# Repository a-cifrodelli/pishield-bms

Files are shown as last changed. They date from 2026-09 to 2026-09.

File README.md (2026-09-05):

# 🛡️ PiShield BMS - Smart UPS & BMS for Raspberry Pi / SBC







**PiShield BMS** è un sistema **UPS (Uninterruptible Power Supply)** personalizzato e modulare dotato di **BMS (Battery Management System)** intelligente basato su Arduino Nano, progettato per garantire l'alimentazione continua e lo spegnimento sicuro (*graceful shutdown*) di un Raspberry Pi o altro Single Board Computer Linux.

> [!WARNING]
> **Work In Progress (WIP)**: Il progetto è in fase di affinamento. La custodia / enclosure stampata in 3D per alloggiare l'elettronica è stata prototipata ma non ha ancora raggiunto una maturità progettuale idonea per la pubblicazione (versione definitiva in corso di perfezionamento).

---

## 💡 Motivazione e Filosofia del Progetto

Il progetto nasce dalla necessità di realizzare un UPS con BMS integrato per Raspberry Pi **senza dover ricorrere alle schede commerciali preassemblate in formato HAT**. 

I moduli HAT commerciali presentano spesso limiti quali:
* Scarsa personalizzazione delle soglie di sicurezza e dei tempi di spegnimento.
* Assenza di protezione termica attiva sulle singole celle 18650.
* Impossibilità di effettuare uno sgancio fisico (*hard cutoff*) per preservare le batterie da scarica profonda e degrado chimico.
* Ingombro rigido sovrapposto al Raspberry Pi.

**PiShield BMS** unisce un economico modulo UPS base con circuito di carica/boost (LX-2BUPS) ad una logica di controllo dedicata su **Arduino Nano**, garantendo la massima sicurezza hardware e flessibilità software.

---

## 📚 Indice della Documentazione

Tutta la documentazione di dettaglio è organizzata nella cartella `docs/`:

* 🛠️ **[Guida alla Ricreazione Hardware (BOM, Cablaggio e Saldature)](docs/recreate.md)**: Elenco componenti (BOM), schema elettrico, istruzioni per le saldature custom ed adattamento del modulo mini UPS base.
* 🚀 **[Guida al Deployment e Installazione Software](docs/deploy.md)**: Configurazione della seriale su Raspberry Pi, script di installazione automatica (`install.sh`), configurazione Systemd e comandi CLI (`pishield-bms`).
* 🧪 **[Piano di Test di Integrazione e Simulazione](docs/TEST_PLAN.md)**: Scenari di test simulati (`TEST_MODE`) per validare spegnimenti, blackout, recovery ed emergency cutoff.

---

## ✨ Funzionalità Principali

* **Doppia Protezione Batterie (Hard Cutoff & Graceful Shutdown)**:
  * **Spegnimento Morbido (Graceful Shutdown)**: Invia una richiesta seriale `SHUTDOWN_REQ` al Raspberry Pi al superamento di soglie di warning (tensione batteria `< 3.2V` o temperatura `> 70°C`).
  * **Sgancio di Emergenza (Hard Cutoff)**: Disattiva il relè KY-019 per staccare fisicamente il pacco batterie in condizioni estreme (tensione batteria `< 3.0V` o temperatura `> 75°C`).
* **Stadi di Protezione Ingressi Analogici**:
  * Lettura filtrata delle tensioni di rete e batteria tramite partitori protetti da fusibili autoripristinanti PPTC (`X16 CF110`) e diodi Schottky (`1N5819`).
* **Monitoraggio Termico**:
  * Misurazione della temperatura su 2 zone/celle tramite termistori NTC 100kΩ.
* **Interfaccia OLED SSD1306 (128x32)**:
  * Visualizzazione in tempo reale di tensioni, temperature, stato della rete, stato delle batterie e calcolo del SOC % con testo in scorrimento continuo.
* **Integrazione Host (Raspberry Pi)**:
  * Client Python (`bms_integration.py` con `config.py` e `.env`) gestito da demone Systemd (`pishield-bms.service`) per la gestione automatica degli ACK di spegnimento e pubblicazione dello stato su broker **MQTT**.
* **Ripristino Automatico (Auto-Recovery)**:
  * Riaggancio automatico del relè quando viene ripristinata la rete elettrica principale e le temperature tornano nella norma.

---

## 🔌 Schema Elettrico di Sintesi

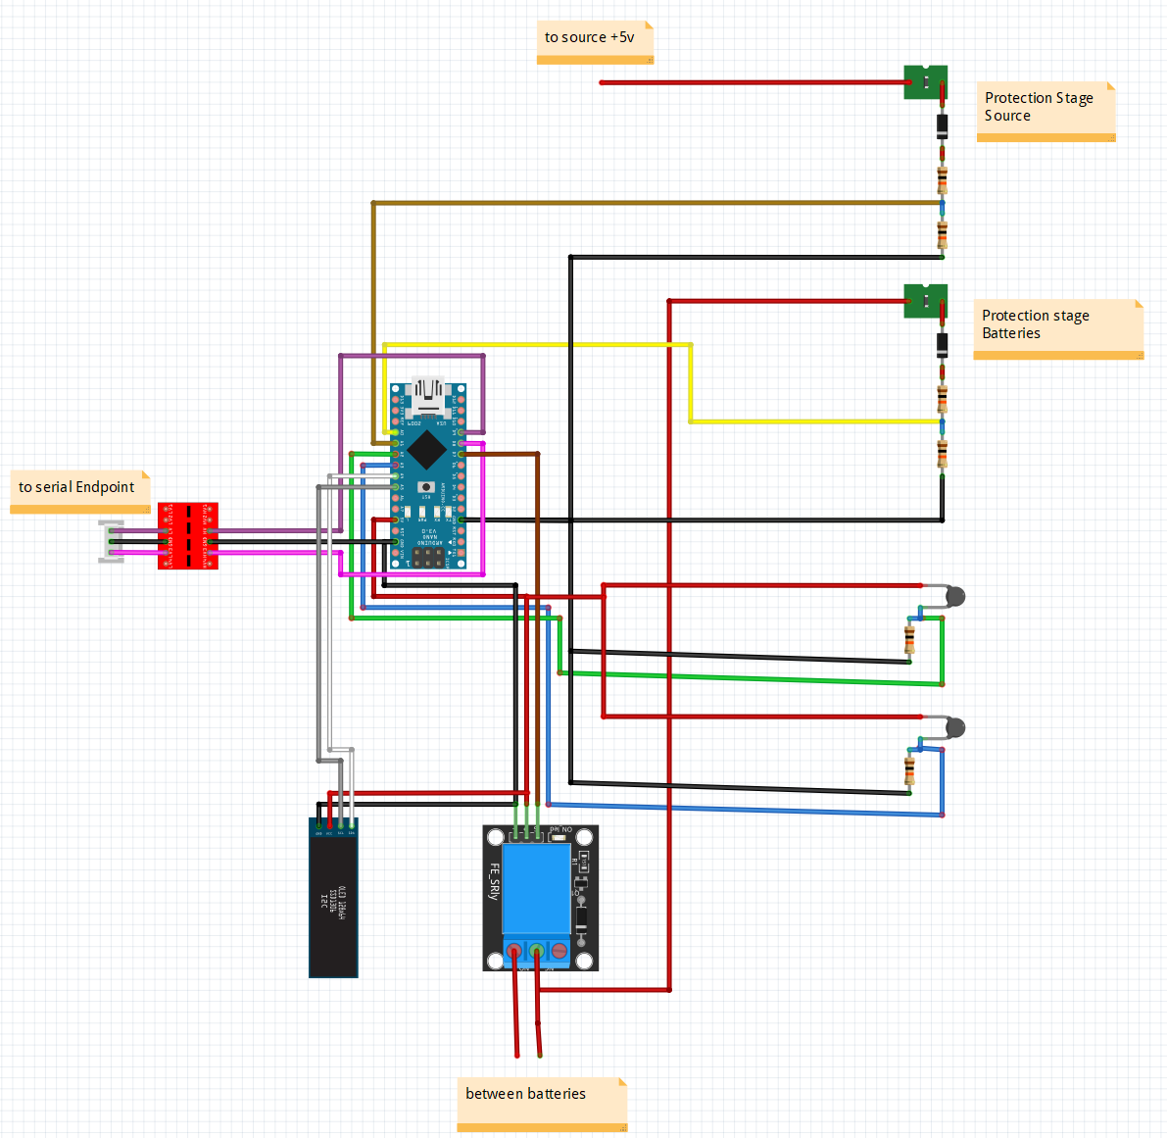
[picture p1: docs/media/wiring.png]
Diagramma di Cablaggio


Per i dettagli completi sul cablaggio e sulle saldature, fare riferimento alla **[Guida alla Ricreazione Hardware](docs/recreate.md)**.

---

## 📄 Licenza

Questo progetto è rilasciato sotto licenza **[MIT License](LICENSE)**.

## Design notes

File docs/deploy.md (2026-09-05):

# 🚀 Guida al Deployment e Installazione Software (PiShield BMS)

Questa guida descrive la procedura di installazione e configurazione del software di integrazione su **Raspberry Pi** (o altro Single Board Computer Linux) per la gestione della comunicazione seriale, il log degli eventi e l'arresto controllato del sistema operativo (*graceful shutdown*).

---

## 📋 Requisiti Preliminari

1. **Sistema Operativo**: Raspberry Pi OS (o altra distribuzione Linux basata su Debian).
2. **Connessione Seriale**:
   * Collegamento UART tra Arduino Nano (tramite traslatore di livello logico 3.3V-5V) ed il Raspberry Pi (su porta `/dev/ttyUSB0` o GPIO UART `/dev/ttyAMA0` / `/dev/ttyS0`).
3. **Abilitazione UART su Raspberry Pi**:
   * Eseguire `sudo raspi-config` -> `Interface Options` -> `Serial Port`.
   * Disabilitare la console di login sulla seriale (*Would you like a login shell to be accessible over serial?* -> **No**).
   * Abilitare l'hardware della porta seriale (*Would you like the serial port hardware to be enabled?* -> **Yes**).
   * In alternativa, verificare che in `/boot/firmware/config.txt` (o `/boot/config.txt`) sia presente la riga:
     ```ini
     enable_uart=1
     ```

---

## ⚡ Installazione Automatica via Script (`install.sh`)

È fornito uno script bash automatizzato in `integration/install.sh` che gestisce la creazione dell'ambiente virtuale Python (`venv`), l'installazione delle dipendenze da `requirements.txt`, la copia dei file in `/opt/pishield_bms`, la configurazione dei permessi e l'attivazione del servizio Systemd `pishield-bms.service`.

### Procedura di Installazione

1. Clonare il repository sul Raspberry Pi:
   ```bash
   git clone https://github.com/username/pishield_bms.git
   cd pishield_bms/integration
   ```

2. Rendere eseguibile ed avviare lo script di installazione con i privilegi di root:
   ```bash
   chmod +x install.sh launcher.sh
   sudo ./install.sh
   ```

---

## ⚙️ Operazioni Eseguite dall'Installer

Lo script di installazione esegue automaticamente i seguenti passaggi:

1. **Installazione Pacchetti di Sistema**:
   * Installa `python3`, `python3-venv` e `python3-pip`.
2. **Setup della Directory di Servizio (`/opt/pishield_bms`)**:
   * Copia i file del modulo: `bms_integration.py`, `config.py`, `requirements.txt`, `launcher.sh` e crea un file `.env` basato su `.env.example`.
3. **Ambiente Virtuale Python (Venv)**:
   * Inizializza l'ambiente virtuale in `/opt/pishield_bms/venv` ed installa le dipendenze isolate definite in `requirements.txt` (`pyserial`, `paho-mqtt`, `python-dotenv`).
4. **Configurazione Symlink Globale**:
   * Crea i link simbolici `/usr/local/bin/pishield-bms` ed `/usr/local/bin/bms_integration` -> `/opt/pishield_bms/launcher.sh` per consentire l'esecuzione da qualsiasi terminale.
5. **Configurazione Permessi Sudoers**:
   * Crea il file `/etc/sudoers.d/pishield-bms` per consentire l'esecuzione del comando `/sbin/shutdown` senza richiesta di password:
     ```text
     ALL ALL=(ALL) NOPASSWD: /sbin/shutdown
     ```
6. **Attivazione Servizio Systemd**:
   * Installa ed abilita `/etc/systemd/system/pishield-bms.service` avviando in background `/opt/pishield_bms/launcher.sh ack`.

---

## 🛠️ Personalizzazione tramite File `.env`

Le impostazioni del client (porta seriale, baudrate, file di log e parametri MQTT) sono centralizzate in `config.py` e possono essere personalizzate modificando il file `/opt/pishield_bms/.env`:

```env
SERIAL_PORT=/dev/ttyUSB0
BAUDRATE=115200
LOGFILE=/var/log/pishield_bms.log
SUFFIX_FILTER=LOG

MQTT_HOST=localhost
MQTT_PORT=8883
MQTT_USER=
MQTT_PASSWORD=
MQTT_TLS=false
MQTT_CA_CERTS=
```

---

## 🔍 Verifiche e Utilizzo CLI

### Verificare lo Stato del Servizio
Per controllare che il servizio in background stia ascoltando correttamente i comandi seriali dall'Arduino:

```bash
systemctl status pishield-bms.service
```

Per consultare i log del servizio tramite `journalctl`:
```bash
journalctl -u pishield-bms.service -f
```

### Utilizzo dei Comandi CLI Manuali
Il comando `pishield-bms` invoca lo script `launcher.sh` eseguendo la logica nel venv dedicato:

* **Test Connessione (PING)**:
  ```bash
  pishield-bms ping
  ```
* **Ascolto e Log Seriale**:
  ```bash
  pishield-bms listen
  ```
* **Lettura Log Salvati**:
  ```bash
  pishield-bms logs -f
  ```
* **Forzatura Spegnimento Manuale**:
  ```bash
  pishield-bms shutdown
  ```

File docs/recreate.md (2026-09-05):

# 🛠️ Guida alla Ricreazione Hardware (PiShield BMS)

Questa guida illustra come assemblare e ricreare l'hardware del sistema **PiShield BMS** seguendo il diagramma di cablaggio ed eseguendo le modifiche necessarie sul modulo UPS base.

> [!WARNING]
> **Work In Progress (WIP)**: Il progetto è in fase di affinamento. La custodia / enclosure stampata in 3D progettata per alloggiare l'intera elettronica è stata prototipata ma non ha ancora raggiunto una maturità progettuale idonea per la pubblicazione (versione definitiva in corso di perfezionamento).

---

## 📦 Bill of Materials (BOM)

| Item | Qty | Specifiche / Descrizione |
| :--- | :---: | :--- |
| **Resistenze 10kΩ** | 4 | Resistenze a strato metallico per i partitori di tensione analogici (A0 e A1) |
| **Resistenze 100kΩ** | 2 | Resistenze fisse per i partitori dei termistori NTC |
| **Termistori NTC 100kΩ** | 2 | Termistori NTC NTC-104 (BETA 3950) per monitoraggio temperatura celle |
| **Fusibili PPTC Autoripristinanti** | 2 | Fusibili PPTC siglati `X16 CF110` (1.1A / 16V) per stadio di protezione ingressi |
| **Diodi Schottky 1N5819** | 2 | Diodi Schottky `1N5819` per protezione da tensioni inverse sui canali ADC |
| **Modulo Relè 5V (KY-019)** | 1 | Modulo relè 5V optoisolato per lo sgancio fisico delle batterie |
| **Display OLED I2C 128x32** | 1 | Display SSD1306 I2C per interfaccia utente locale |
| **Modulo Mini UPS (LX-2BUPS)** | 1 | Scheda UPS 3A / 5V boost con alloggiamento per 2x 18650 in parallelo |
| **Arduino Nano V3** | 1 | Microcontrollore ATmega328P (logica 5V) |
| **Logic Level Shifter (CYT1076)** | 1 | Convertitore di livello logico bidirezionale 3.3V <-> 5V a 4 canali per bus UART |
| **Modulo Uscita USB-C Breakout** | 1 | Modulo USB-C con resistenze 56kΩ su CC1 e CC2 (configurazione 3A Source) |
| **Condensatore ceramico 0.1µF** | 1 | Condensatore di disaccoppiamento tra VCC e GND su Arduino Nano |
| **Resistenza 1kΩ** | 1 | Resistenza in serie sulla linea seriale TX Arduino -> Level Shifter |
| **Nastro Kapton e Cavi di Potenza** | - | Nastro isolante Kapton e cavi AWG18-20 (potenza) e AWG24-26 (segnali) |

---

## 📸 Componenti e Diagramma di Cablaggio

### Modulo Mini UPS di Base (LX-2BUPS)
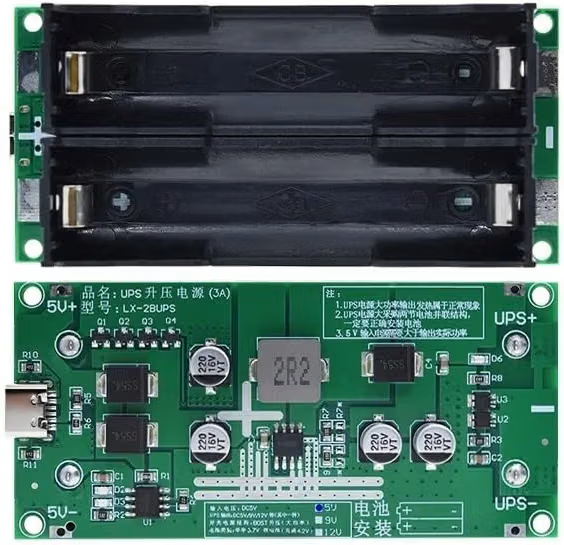
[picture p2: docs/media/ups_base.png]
Modulo Mini UPS Base


### Schema Elettrico Globale
Diagramma di Cablaggio

---

## 🔬 Saldature e Modifiche Hardware Custom

Per integrare la logica BMS ed il relè di protezione con il modulo UPS base (LX-2BUPS), è necessario eseguire le seguenti modifiche hardware:

### 1. Dissaldatura dai Moduli Originali
1. **Contatti Batterie**: Dissaldare con cura le linguette o i contatti a molla originali delle batterie dal PCB dell'UPS LX-2BUPS (o intercettare i terminali del connettore batteria).
2. **Uscita 5V Originale**: Dissaldare i pin/connettori d'uscita 5V dal PCB dell'UPS per reindirizzarli al modulo USB-C dedicato.

### 2. Collegamento del Relè di Sgancio (KY-019)
* Saldare cavi di potenza con sezione adeguata (**AWG 18-20**) tra il polo positivo del pacco batterie (2x 18650) ed i morsetti `COM` e `NO` del relè KY-019.
* **Sicurezza del Pacco Batterie in Parallelo**:
  > [!NOTE]
  > L'analisi del PCB del modulo LX-2BUPS conferma che le due celle 18650 sono collegate nativamente in **parallelo puro** alla stessa linea di carica/scarica. È quindi del tutto sicuro interrompere il polo positivo comune del ramo batterie tramite il relè: il modulo continuerà a gestire il bilanciamento passivo e la carica/scarica in modo bilanciato senza rischiare sbilanciamenti di cella.

### 3. Modulo Uscita USB-C con Configurazione 3A (Source)
* Collegare le piazzole di uscita 5V boost del modulo UPS (`UPS+` e `UPS-`) agli ingressi di alimentazione del modulo USB-C breakout.
* Assicurarsi che sul breakout USB-C i pin **CC1** e **CC2** siano pull-uppati a VCC tramite resistenze da **56kΩ**. Questa configurazione informa il carico (ad esempio una Raspberry Pi 4 o 5 gestita come *Sink*) che la sorgente USB-C è in grado di erogare fino a **3A a 5V**.

### 4. Stadi di Protezione Ingressi Analogici Arduino
Realizzare i due stadi di protezione (per la sorgente di rete e per la batteria) facendo riferimento al [Diagramma di Cablaggio](#schema-elettrico-globale):

* **Ingresso Rete**: Collegare il polo positivo dell'ingresso USB-C principale allo stadio di protezione Sorgente (PPTC `X16 CF110` -> Diodo `1N5819` -> partitore 10kΩ/10kΩ) con punto di misura collegato al pin `PINRETE` (**A1** Arduino).
* **Ingresso Batteria**: Collegare il polo positivo a valle del relè allo stadio di protezione Batterie (PPTC `X16 CF110` -> Diodo `1N5819` -> partitore 10kΩ/10kΩ) con punto di misura collegato al pin `PINBATT` (**A0** Arduino).

### 5. Sensori di Temperatura NTC e Display OLED
* Collegare i due termistori NTC 100kΩ in serie con la relativa resistenza fissa da 100kΩ verso i pin **A2** (`PINNTC1`) e **A3** (`PINNTC2`).
* Collegare il display OLED I2C 128x32: `SDA` -> **A4**, `SCL` -> **A5**, `VCC` -> **5V**, `GND` -> **GND**.

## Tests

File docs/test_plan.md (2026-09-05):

# 🧪 Piano di Test di Integrazione PiShield BMS

Questo documento illustra i piani di test per validare la logica del BMS **PiShield BMS**.
Imposta `#define TEST_MODE true` in `config.h` per abilitare i comandi seriali.

---

<details open>
<summary><b>🌩️ 1. Blackout con batteria debole (Warning)</b></summary>

* **Input Seriale:** `SIM_GRID 0` poi `SIM_BATT 3.1`
* **Stato Simulato:** Manca la rete (Offgrid) e la batteria è scesa sotto la soglia di warning (3.2V).
* **Risultato Atteso:** 
  > Il sistema entra in stato `BAT LOW` e `OFFGRID`.
  > Stampa **`SHUTDOWN_REQ`** e inizia un conto alla rovescia (60s) avvisando `SHUTDOWN IMMINENT`. 
  > Il relè rimane *chiuso*.

</details>

<details>
<summary><b>🔌 2. Ripristino Rete durante il Countdown</b></summary>

* **Input Seriale:** `SIM_GRID 5.0` *(durante il test 1)*
* **Stato Simulato:** La corrente elettrica torna prima dello scadere del timer di sicurezza.
* **Risultato Atteso:** 
  > Il sistema riconosce `ONGRID`. 
  > Il timer di spegnimento viene **interrotto e annullato**. 
  > Il sistema riprende il normale funzionamento, il relè non stacca.

</details>

<details>
<summary><b>🤝 3. Acknowledge (Spegnimento RPi)</b></summary>

* **Input Seriale:** `SIM_GRID 0` ➔ `SIM_BATT 3.1` ➔ `ACK`
* **Stato Simulato:** Blackout e batteria debole. Il Raspberry Pi risponde con "ACK" per confermare lo spegnimento imminente.
* **Risultato Atteso:** 
  > Il sistema riceve `ACK` e stampa **`WAITING`**. 
  > Il cooldown viene forzatamente **ridotto a 30s** per velocizzare lo stacco di sicurezza.

</details>

<details>
<summary><b>💀 4. Batteria Critica (Hard Cutoff)</b></summary>

* **Input Seriale:** `SIM_GRID 0` poi `SIM_BATT 2.9`
* **Stato Simulato:** La batteria scende sotto la soglia letale (3.0V). Rischio di danneggiamento chimico.
* **Risultato Atteso:** 
  > Nessun conto alla rovescia. 
  > Stampa **`!!! EMERGENCY CUTOFF TRIGGERED !!!`** con reason **`BATTERY_CRITICAL_AND_OFFGRID`** e **stacca il relè istantaneamente** per salvare la batteria.

</details>

<details>
<summary><b>🔥 5. Surriscaldamento (Warning)</b></summary>

* **Input Seriale:** `SIM_TEMP 71`
* **Stato Simulato:** L'NTC rileva una temperatura superiore ai 70°C.
* **Risultato Atteso:** 
  > Il sistema entra in `TEMP WARNING`. 
  > Stampa **`SHUTDOWN_REQ`** e avvia il cooldown per far spegnere dolcemente il RPi.

</details>

<details>
<summary><b>🌋 6. Surriscaldamento Critico (Thermal Cutoff)</b></summary>

* **Input Seriale:** `SIM_TEMP 80`
* **Stato Simulato:** Temperatura oltre i 75°C. Rischio di esplosione o incendio.
* **Risultato Atteso:** 
  > Stampa **`!!! EMERGENCY CUTOFF TRIGGERED !!!`** con reason **`TEMPERATURE_CRITICAL`** e **stacca il relè istantaneamente**.

</details>

<details>
<summary><b>🛑 7. Spegnimento Manuale Diretto</b></summary>

* **Input Seriale:** `SHUTDOWN_NOW`
* **Stato Simulato:** Utente forza lo spegnimento immediato per manutenzione.
* **Risultato Atteso:** 
  > Stampa **`SHUTDOWN REASON: user_choice`**. 
  > Inizia a stampare **`SHUTDOWN IMMINENT - COOLDOWN: ...`** ogni secondo in modo fluido.
  > Attende 15 secondi esatti e poi disattiva il relè. Non è interrompibile se torna la rete.

</details>

<details>
<summary><b>✅ 8. Ripristino da Sicurezza</b></summary>

* **Input Seriale:** `SIM_RESET` (oppure `SIM_GRID 5.0` e `SIM_TEMP 25`)
* **Stato Simulato:** Rete elettrica ripristinata e temperature tornate normali.
* **Risultato Atteso:** 
  > Stampa **`[RECOVERY] Rete ripristinata e temperatura sicura. Riattacco il rele'.`**.
  > I log tornano a indicare `ONGRID` e `T:OK`. Il BMS rientra a regime normale ricaricando la batteria.

</details>

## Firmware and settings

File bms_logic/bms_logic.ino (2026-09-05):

#include "config.h"
#include "sensor.h"
#include "display.h"
#include "log.h"
#include "terminal.h"
#include "shutdown.h"
#include "bms_state.h"
Shudown_Req shutdown_req;
bool cutoff_now = false;

void executeEmergencyCutoff(const __FlashStringHelper* reason) {
  if (cutoff_now) return; // Evita di spammare la seriale se è già staccato
  
  digitalWrite(RELAYPIN, LOW); // SGANCIO FISICO IMMEDIATO
  cutoff_now = true;

  Serial.println(F("\n================================="));
  Serial.print(F("!!! EMERGENCY CUTOFF TRIGGERED !!!\nREASON: "));
  Serial.println(reason);
  Serial.println(F("=================================\n"));
}

// Le logiche di shutdown sono state spostate in shutdown.cpp

void setup() {
  Serial.begin(115200);
  delay(100); // Breve assestamento per la seriale

  Serial.println(F("\n================================="));
  Serial.println(F("   PISHIELD BMS - BOOTING...     "));
  Serial.println(F("================================="));
  
  Serial.println(F("[BOOT] Setup Pin I/O..."));
  pinMode(RELAYPIN, OUTPUT);
  pinMode(PINBATT, INPUT);
  pinMode(PINRETE, INPUT);
  pinMode(PINNTC1, INPUT);
  pinMode(PINNTC2, INPUT);
  
  Serial.println(F("[BOOT] Init Shutdown Logic..."));
  initRequestShutdown();
  
  Serial.println(F("[BOOT] Init OLED Display..."));
  initDisplay();
  
  Serial.println(F("[BOOT] Attivazione Rele' OUT..."));
  digitalWrite(RELAYPIN, HIGH);
  
  Serial.println(F("================================="));
  Serial.println(F("     SISTEMA PRONTO ALL'USO      "));
  Serial.println(F("================================="));

  delay(2000);
}

void loop() {
  // LETTURE SENSORI
  float vbatt = readBattVoltage();
  float soc = voltageToSOC(vbatt);
  float temp1 = readTemperature(PINNTC1);
  float temp2 = readTemperature(PINNTC2);
  float temp  = max(temp1, temp2); // prende la peggiore
  float vrete = readGridVoltage();

  // AGGIORNO STATO
  updateBMSState(vbatt, temp, vrete);

  // --- CUTOFF IMMEDIATI ---
  if(tempstate == TEMP_CRITICAL){
    executeEmergencyCutoff(F("TEMPERATURE_CRITICAL"));
  }
  if((batstate == BAT_CRITICAL) && (gridstate == OFFGRID)){
    executeEmergencyCutoff(F("BATTERY_CRITICAL_AND_OFFGRID"));
  }

  // --- SHUTDOWN RITARDATI (WARNING) ---
  if (!cutoff_now) {
    bool need_shutdown = false;
    if (tempstate == TEMP_WARNING) need_shutdown = true;
    if ((batstate == BAT_LOW) && (gridstate == OFFGRID)) need_shutdown = true;

    if (need_shutdown) {
      requestShutdown();
      shutdown_req.can_interrupt_shutdown = false; // L'allarme è attivo, spegnimento in corso
    } else {
      // Tutto regolare. Se c'era uno spegnimento in corso (non forzato dall'utente), annullalo.
      if (!shutdown_req.user_forced) {
        shutdown_req.can_interrupt_shutdown = true;
      }
    }
  }

  // AUTO-RECOVERY (Es. per Scenario 8 del piano di test)
  if (cutoff_now && gridstate == ONGRID && tempstate == TEMP_NORMAL && !shutdown_req.user_forced) {
     Serial.println(F("[RECOVERY] Rete ripristinata e temperatura sicura. Riattacco il rele'."));
     cutoff_now = false;
     digitalWrite(RELAYPIN, HIGH);
  }
  //SERIALE E COOLDOWN TIME-SPLICING
  checkShutdownCooldown();
  handleSerial();
  //LOG &DISPLAY
  updateDisplay(vbatt, temp1, temp2, vrete, soc, batstate, tempstate, gridstate);
  periodic_log(vbatt, temp1, temp2, vrete, soc, batstate, tempstate, gridstate);
  delay(GLOBAL_TICK);
}

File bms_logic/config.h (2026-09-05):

#ifndef CONFIG
#define CONFIG

// ===============================
// DISPLAY
// ===============================
#define SCREEN_WIDTH 128
#define SCREEN_HEIGHT 32

// ===============================
// HARDWARE PINS
// ===============================
#define PINBATT A0
#define PINRETE A1
#define PINNTC1 A2   // NTC cella 1
#define PINNTC2 A3   // NTC cella 2
#define RELAYPIN 4    // relay sgancio batterie
#define RXPIN 8   // RX Arduino (collegato a TX RPi)
#define TXPIN 9   // TX Arduino (collegato a RX RPi)

// ===============================
// PARTITORI (da adattare ai tuoi valori)
// ===============================
const float R1 						= 10000.0;   // 10kΩ
const float R2 						= 10000.0;   // 10kΩ

// ===============================
// NTC 
// ===============================
const float R_FIXED 			    = 100000.0; // resistenza fissa 100k
const float BETA 					= 3950.0;      // parametro del datasheet
const float T0 						= 298.15;        // 25 °C in Kelvin
const float R0 						= 100000.0;      // resistenza NTC a 25°C

// ===============================
// SOGLIE DI SICUREZZA
// ===============================
const float VBATLOW					= 3.2;//3.3;   // V soglia warning
const float VBATHIGH     			= 3.7;//3.7;   // V isteresi riattacco
const float VBATCRITICAL 			= 3.0;   // V hard cutoff

const float TEMPWARN      			= 70.0;  // °C warning
const float TEMPCRITICAL  			= 75.0;  // °C hard cutoff
const float TEMPNORMAL          = 40;

const float GRIDLOW         = 4.0;

// Gli enumeratori di stato sono stati spostati in bms_state.h

// ===============================
// CONFIG FLAG
// ===============================
#define SERIAL_DEBUG true   // se true abilita PING/PONG e log verbosi
#define TEST_MODE false      // se true usa dati fittizi per i sensori (mock)
#if TEST_MODE
#define MOCK_DEFAULT_VBATT 4.0
#define MOCK_DEFAULT_VRETE 5.0
#define MOCK_DEFAULT_TEMP 25.0
#endif
#define GLOBAL_TICK 200

// ===============================
// COOLDOWN
// ===============================
const unsigned int MIN_SHUTDOWN_COOLDOWN = 30000;
const unsigned int MAX_SHUTDOWN_COOLDOWN = 60000;
const unsigned int USER_CHOICE_SHUTDOWN_COOLDOWN = 15000;

typedef struct Shudown_Req{
  bool requested;
  bool can_interrupt_shutdown;
  bool user_forced;
  unsigned long started_at;
  unsigned long cooldown;
  unsigned long cooldown_lastprint;
};

#endif

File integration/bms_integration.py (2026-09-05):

#!/usr/bin/env python3
import argparse
import serial
import sys
import time
import os
import threading
import atexit
import paho.mqtt.client as mqtt

import config

SERIAL_CONN = None

def publish_mqtt(topic: str, message: str,
                 host=config.MQTT_HOST, port=config.MQTT_PORT,
                 user=config.MQTT_USER, password=config.MQTT_PASSWORD,
                 tls_enabled=config.MQTT_TLS, tls_ca=config.MQTT_CA_CERTS,
                 keepalive=60):
    try:
        client = mqtt.Client()
        if user and password:
            client.username_pw_set(user, password)
        if tls_enabled:
            if tls_ca:
                client.tls_set(ca_certs=tls_ca)
            else:
                client.tls_set()  # usa certificati default
        client.connect(host, port, keepalive)
        client.publish(topic, message)
        client.disconnect()
        print(f"MQTT pubblicato → {topic}: {message}")
    except Exception as e:
        print(f"Errore MQTT: {e}")

def open_serial():
    global SERIAL_CONN
    SERIAL_CONN = serial.Serial(config.SERIAL_PORT, config.BAUDRATE, timeout=1)
    return SERIAL_CONN

def cleanup():
    if SERIAL_CONN and SERIAL_CONN.is_open:
        SERIAL_CONN.close()
        print("Seriale chiusa correttamente.")

def write_log(line: str):
    """Scrive log filtrato su file"""
    if line.endswith(config.SUFFIX_FILTER):
        return
    try:
        with open(config.LOGFILE, "a") as f:
            f.write(line.strip() + "\n")
    except Exception as e:
        print(f"Errore scrittura log su {config.LOGFILE}: {e}")

def read_serial(ser):
    """Legge una riga dalla seriale"""
    try:
        line = ser.readline().decode(errors="ignore").strip()
        if line:
            print(line)       # output sempre completo a schermo
            write_log(line)   # log filtrato
        return line
    except Exception:
        return ""

# ---------------------------
# COMMANDS
# ---------------------------
def cmd_shutdown():
    ser = open_serial()
    ser.write(b"SHUTDOWN_NOW\n")
    print("Inviato: SHUTDOWN_NOW")

def cmd_ping():
    ser = open_serial()
    ser.write(b"PING\n")
    print("Inviato: PING")
    time.sleep(0.5)
    read_serial(ser)

def ack_listener():
    """Thread che risponde con ACK quando riceve SHUTDOWN_REQ"""
    ser = open_serial()
    print("ACK listener attivo... (CTRL+C per uscire)")
    try:
        while True:
            line = read_serial(ser)
            if line == "SHUTDOWN_REQ":
                ser.write(b"ACK\n")
                print("Inviato: ACK")
    except KeyboardInterrupt:
        print("\nACK listener interrotto.")

def cmd_ack():
    ser = open_serial()
    print("Listener ACK avviato, in attesa di SHUTDOWN_REQ...")
    while True:
        line = ser.readline().decode(errors="ignore").strip()
        if not line:
            continue
        print("Ricevuto:", line)

        if line == "SHUTDOWN_REQ":
            ser.write(b"ACK\n")
            print("Inviato: ACK")

            # Pubblica su MQTT
            publish_mqtt("system/shutdown", "ACK sent, shutting down")

            # Spegni Raspberry
            os.system("sudo shutdown -h now")
            break

def cmd_listen():
    """Resta in ascolto e gestisce seriale + log"""
    ser = open_serial()
    print("In ascolto sulla seriale... (CTRL+C per uscire)")
    try:
        while True:
            read_serial(ser)
    except KeyboardInterrupt:
        print("\nInterrotto.")

SKIP_THRESHOLD = 3  # salva solo 1 entry ogni 3 righe

def cmd_logs(follow=False):
    """Mostra log salvati (già filtrati) con skip threshold globale"""
    if not os.path.exists(config.LOGFILE):
        print(f"Nessun log presente in {config.LOGFILE}.")
        return

    counter = 0

    # stampa log attuale filtrando
    with open(config.LOGFILE, "r") as f:
        for line in f:
            line = line.strip()
            if counter % SKIP_THRESHOLD == 0:
                print(line)
            counter += 1

    if follow:
        print("\n--- Seguendo i log (CTRL+C per uscire) ---\n")
        with open(config.LOGFILE, "r") as f:
            f.seek(0, os.SEEK_END)
            counter = 0
            try:
                while True:
                    line = f.readline()
                    if not line:
                        time.sleep(0.5)
                        continue
                    line = line.strip()
                    if counter % SKIP_THRESHOLD == 0:
                        print(line)
                    counter += 1
            except KeyboardInterrupt:
                print("\nUscita da live logs.")


# ---------------------------
# MAIN ENTRYPOINT
# ---------------------------
def main():
    parser = argparse.ArgumentParser(description="PiShield BMS - Client seriale e daemon di integrazione per Raspberry Pi")
    sub = parser.add_subparsers(dest="cmd")

    sub.add_parser("shutdown", help="Invia SHUTDOWN_NOW")
    sub.add_parser("ack", help="Resta in attesa di SHUTDOWN_REQ e risponde ACK")
    sub.add_parser("ping", help="Invia PING e mostra risposta")
    sub.add_parser("listen", help="Ascolta continuamente la seriale e logga (filtrato)")
    logs_parser = sub.add_parser("logs", help="Mostra log salvati")
    logs_parser.add_argument("-f", action="store_true", help="Segui log live")

    args = parser.parse_args()

    if args.cmd == "shutdown":
        cmd_shutdown()
    elif args.cmd == "ack":
        cmd_ack()
    elif args.cmd == "ping":
        cmd_ping()
    elif args.cmd == "listen":
        cmd_listen()
    elif args.cmd == "logs":
        cmd_logs(follow=args.f)
    else:
        parser.print_help()

if __name__ == "__main__":
    atexit.register(cleanup)
    main()

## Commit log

2026-09-05 feat: initial release of PiShield BMS hardware, firmware & docs
    [mini_ups.fzz]
2026-09-05 wiring: update schematics
    [mini_ups.fzz]

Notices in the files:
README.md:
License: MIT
